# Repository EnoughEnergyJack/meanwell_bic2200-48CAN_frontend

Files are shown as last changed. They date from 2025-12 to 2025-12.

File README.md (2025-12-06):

# Meanwell BIC2200 Front-End Controller

- Many companies develop things that are critical for development, but are not needed for their products/IP. This is one of those developments.
- It is a front-end PCB/Screen that allows you to control the Meanwell BIC2200-48CAN as if it were a Bench PSU, very simple, mostly generated by AI prompts.
- The psu itself is great because it is bidirectional, you can set it as a supply or a regenerative load, up to ~2.2kW.
- If this is useful to you, give Enough Energy Ltd a shoutout, but to be clear this was mostly a "quick and dirty"(but very effective) PCB to help our other developments along.

## Features

- **Display Modes**
  - Main display: Real-time voltage, current, power, and energy monitoring
  - Limits display: Voltage and current setpoint configuration
  
- **Controls**
  - Rotary encoders for voltage (38-65V) and current (0-45A positive, -38A to 0A negative) adjustment
  - Dedicated buttons for output control, view switching, and setpoint confirmation
  
- **Real-Time Monitoring**
  - Output voltage and current readings
  - Power consumption (watts)
  - Energy consumption tracking (watt-hours)
  - Runtime timer
  - Output status indicator
  
- **CAN Bus Communication**
  - Bidirectional communication with Meanwell power supply
  - Automatic setpoint echo verification
  - Real-time data polling

## Hardware

The project uses a dedicated PCB designed specifically for the Arduino Uno. The PCB integrates all required hardware components:

- **16x4 Character LCD Display** (HD44780-compatible)
- **2x Rotary Encoders** with integrated push buttons (voltage and current adjustment)
- **4x Push Buttons** (VIEW, CHNG I, SET BUFFER, OUTPUT)
- **MCP2515 CAN Controller** with CAN transceiver
- **Power Input** (barrel jack connector)
- **Pin Headers** for Arduino Uno connection
- **CAN Bus Connector** for power supply communication

### Wiring Harness

For wiring harness details and external connections, refer to the schematic in the documentation:
- **Schematic**: See `Documentation/Meanwell_FE v17.pdf` for complete wiring diagrams and harness specifications

The PCB is designed to mount directly onto an Arduino Uno, with all components and connections pre-routed on the board.

## Software Dependencies

### Arduino Libraries
- `LiquidCrystal` - LCD display control (included with Arduino IDE)
- `mcp_can` - MCP2515 CAN controller library
- `SPI` - SPI communication (included with Arduino IDE)
- `Encoder` - Rotary encoder input handling

### Installation

1. Install the required libraries via Arduino Library Manager:
   ```
   - mcp_can (by Seeed Studio or compatible)
   - Encoder (by Paul Stoffregen)
   ```

2. Clone or download this repository.

3. Mount the dedicated PCB onto your Arduino Uno (see schematic for pin alignment)

4. Connect the wiring harness as specified in the schematic (`Documentation/Meanwell_FE v17.pdf`)

5. Open `Meanwell/Meanwell.ino` in the Arduino IDE

6. Configure pin assignments in `Meanwell/config.h` if needed (defaults should work with the PCB)

7. Upload the firmware to your Arduino board

## Pin Configuration

Default pin assignments (defined in `config.h`):

| Component | Pin | Description |
|---|-----|---|
| LCD RS | A2 | Register select |
| LCD EN | A3 | Enable |
| LCD D4-D7 | 5, 4, 3, A4 | Data lines (4-bit mode) |
| Voltage Encoder CLK | 6 | Clock pin |
| Voltage Encoder DT | 7 | Data pin |
| Current Encoder CLK | A0 | Clock pin |
| Current Encoder DT | 9 | Data pin |
| SET BUF Button | A1 | Set buffer values |
| OP TOGGLE Button | A5 | Output enable/disable |
| VIEW Button | 8 | Display mode toggle |
| CHNG I Button | 2 | Current direction toggle |
| CAN CS | 10 | CAN controller chip select |

## Usage

### Basic Operation

1. **Setting Voltage and Current Limits**
   - Press VIEW to enter Limits Display mode
   - Rotate voltage encoder to set desired voltage (38-65V)
   - Rotate current encoder to set positive current limit (0-45A)
   - Press CHNG I to switch to negative current editing
   - Rotate current encoder to set negative current limit (-38A to 0A)
   - Press SET BUF to apply settings to the power supply

2. **Enabling Output**
   - Configure desired limits (see above)
   - Press OP TOGGLE to enable output
   - Monitor real-time values on Main Display

3. **Monitoring**
   - Main Display shows:
     - Output voltage (V)
     - Output current (A)
     - Power consumption (W)
     - Energy consumed (Wh)
     - Runtime timer (seconds)
     - Output status (ON/OFF)

For detailed user instructions, see [USER_GUIDE.md](USER_GUIDE.md).

## Technical Details

### CAN Communication

- **Baud Rate**: 250 kbps
- **CAN ID TX**: 0xC0300 (commands to power supply)
- **CAN ID RX**: 0x800C0200 (responses from power supply)
- **Protocol**: PMBus-compatible commands over CAN
- **Mechanism**: Request-response pattern (see [CAN Messaging Protocol](Documentation/CAN_MESSAGING.md) for details)

- Voltage setpoint (CMD_VOUT_SET: 0x20)
- Current setpoint (CMD_IOUT_SET: 0x30)
- Reverse current setpoint (CMD_REVERSE_IOUT_SET: 0x130)
- Output enable/disable (CMD_OPERATION: 0x00)
- Read voltage (CMD_READ_VOUT: 0x60)
- Read current (CMD_READ_IOUT: 0x61)

### Display Update Rates

- Main Display: 20 Hz (50ms intervals)
- Limits Display: 2 Hz (500ms intervals)
- CAN polling: 10 Hz (100ms intervals)

### Energy Tracking

- Energy meter resets when output is enabled
- Power calculation uses filtered values for stability
- Energy integration: `E = ∫ P dt` (watt-hours)

## Development

### Building

1. Ensure all required libraries are installed
2. Open `Meanwell/Meanwell.ino` in Arduino IDE
3. Select your board and port
4. Compile and upload

### Debugging

- Serial output available at 115200 baud
- CAN communication status indicated by blinking `[ ]` on display
- Setpoint echo verification ensures commands are received

## Documentation

- [User Guide](USER_GUIDE.md) - Complete user manual
- [CAN Messaging Protocol](Documentation/CAN_MESSAGING.md) - Detailed explanation of the request-response CAN communication mechanism
- [Documentation/](Documentation/) - Hardware datasheets and specifications
- [MEANWELL.dbc](Documentation/MEANWELL.dbc) - CAN bus DBC file for protocol reference

## License

MIT

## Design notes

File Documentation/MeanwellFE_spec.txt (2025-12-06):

Here is a complete and concise summary of the PCB design in a structured document format:

---

## **Programmable Power Supply Front-End Controller – Design Summary**

### **Overview**

This design implements a front-end user interface and control board for a **Meanwell programmable power supply**, managed via **CAN bus** using an **Arduino microcontroller**. The interface provides user control over voltage and current settings, displays real-time feedback, and communicates settings to the power supply over CAN.

---

### **1. Functional Description**

#### **Main Functions**:

* Allow users to set and buffer **voltage (V)** and **current (I)** values.
* Display real-time output values from the power supply.
* Enable or disable the output via a control button.
* Transmit buffered settings via CAN bus when prompted.

---

### **2. Major Components**

#### **Microcontroller Unit (MCU)**

* **Arduino-compatible board** with:

  * Digital I/O lines for button and display interface
  * CAN bus support via a CAN transceiver module (e.g., MCP2515)

#### **Display**

* **Character LCD** with **parallel interface** (likely HD44780-compatible)

  * Controlled via 4-bit mode (RS, E, D4–D7)
  * Displays:

    * Voltage and current setpoints (`Vset`, `Iset`)
    * Buffered values (`Vbuf`, `Ibuf`)
    * Output readings (`Vout`, `Iout`)
    * Output state (`OP: 1` for ON)

#### **User Input Controls**

* **Two rocker switches**:

  * One for **voltage** adjustment (V+ / V−)
  * One for **current** adjustment (I+ / I−)
* **Two pushbuttons**:

  * `Set Buf`: Sends buffered values to the power supply
  * `OP On/Off`: Toggles power output state

#### **CAN Interface**

* Uses standard **CANH/CANL lines**
* Powered via onboard **+5V** supply
* Connected to Arduino via SPI-compatible CAN module

---

### **3. Power Supply**

* Board is powered via **+5V** input
* Onboard decoupling capacitors for voltage stability
* Supports powering external components including display and CAN transceiver

---

### **4. Connectors**

* **CAN Bus Output Connector**:

  * CANH, CANL
  * +5V and GND
* **Optional headers** for debug or expansion

---

### **5. Signal Flow Summary**

1. **User** adjusts V/I using rocker switches.
2. Adjustments update buffer values (`Vbuf`, `Ibuf`), displayed on screen.
3. **Set Buf** button transmits values to power supply via CAN.
4. **Output button** toggles output enable/disable.
5. Display updates all states and measurements dynamically.

---

### **6. Software Considerations**

* Arduino firmware handles:

  * Button debouncing and state management
  * LCD control using `LiquidCrystal` library
  * CAN bus communication using `MCP_CAN` library or equivalent
  * Control logic for buffering and output toggling

---

### **7. Physical Layout**

* **Compact PCB design** with:

  * Front-facing display
  * Top-mounted rocker and push buttons
  * Rear or side connectors for CAN and power
  * Through-hole and possibly SMD components for ease of assembly

---

### **Applications**

* Laboratory power supply control
* Remote-controlled power systems
* Embedded development requiring voltage/current staging

---

Let me know if you’d like this turned into a PDF or if you want a matching Arduino sketch to go with this design.

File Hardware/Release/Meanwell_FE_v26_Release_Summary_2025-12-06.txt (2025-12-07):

Meanwell_FE v26 - JLCPCB Release Summary
==========================================
Date: 2025-12-06
Version: v26
Board: Meanwell_FE v26

FILES PREPARED:
---------------
1. Meanwell_FE_v26_JLC_PCB.zip
   - Contains all Gerber files and drill file for PCB manufacturing
   - All files in root directory as required by JLCPCB

2. Meanwell_FE_v26_JLCBOM_2025-12-06.csv
   - Bill of Materials in JLCPCB format
   - 21 unique component types
   - 37 total components

3. Meanwell_FE_v26_JLCPNP_2025-12-06.csv
   - Pick and Place file in JLCPCB format
   - 37 components (top and bottom combined)
   - Coordinates in millimeters

COMPONENT STATUS:
-----------------
✓ Components with JLCPCB Part Numbers (10 types):
  - 100nF 0603 capacitors (C1, C6, C8): C105907
  - 1uF 0603 capacitors (C9, C12): C15849
  - 10uF 0805 capacitors (C34, C35, C36, C37): C2922480
  - 120R 0603 resistors (R2, R4): C122081
  - 1k 0603 resistors (R1, R3): C22765
  - M7 diode (D1): C95872
  - NCP1117ST50T3G voltage regulator (U7): C156196
  - CRE1S0505S DC-DC converter (PS1): C7465127
  - 8MHz ceramic resonator (Y1): C341522
  - 43650-0424 connector (J1): C492464

⚠ Components Needing JLCPCB Part Numbers (11 types):
  - 164G_FC_BW-3LP LCD display (DS1) - May need to source separately
  - ESP32-DEVKITC-32E module (U2) - Module, may need extended parts
  - MCP2515-I/SO CAN controller (U1) - Check JLCPCB availability
  - ISO1050DUB CAN transceiver (U4) - Check JLCPCB availability
  - C143785 encoder (VR1, VR2) - PEC12R-4215F-N0024
  - Pin headers (JP2, JP3, JP4, U$2) - Through-hole, may be DNF
  - Switches (CHANGE, OUTPUT, SET_BUFFER, VIEW, I_DOWN, I_UP, V_DOWN, V_UP) - Through-hole, DNF
  - JP1 header - DNF

DNF (Do Not Fit) COMPONENTS:
-----------------------------
These components are marked as DNF and will be hand-soldered or sourced separately:
  - JP1 (1X02 header)
  - I_DOWN, I_UP, V_DOWN, V_UP (momentary switches)
  - All through-hole components

NOTES:
------
1. PCB Manufacturing:
   - Upload Meanwell_FE_v26_JLC_PCB.zip to JLCPCB
   - Board appears to be 2-layer based on file structure
   - Verify board dimensions and specifications during upload

2. Assembly Service:
   - Upload Meanwell_FE_v26_JLCBOM_2025-12-06.csv for BOM
   - Upload Meanwell_FE_v26_JLCPNP_2025-12-06.csv for PnP
   - Review component availability before ordering
   - Many components may need to be sourced as "Extended" parts or separately

3. Component Sourcing:
   - LCD display (164G_FC_BW-3LP) likely needs separate sourcing
   - ESP32 module may be available as extended part
   - Through-hole components (switches, headers) are DNF
   - Verify all IC part numbers match JLCPCB inventory

4. Quality Checks:
   - ✓ BOM component count matches PnP count (37 components)
   - ✓ All designators accounted for
   - ✓ Coordinates in millimeters
   - ✓ Top/bottom layers properly designated
   - ⚠ Some components need JLCPCB part number verification

NEXT STEPS:
----------
1. Review BOM file and add missing JLCPCB part numbers
2. Verify PnP coordinates look correct (compare with Gerber preview)
3. Check component availability on JLCPCB website
4. Update BOM with any part number corrections
5. Upload all files to JLCPCB
6. Review JLCPCB preview carefully before ordering
7. Consider ordering small prototype quantity first (5 boards)

PROCESSING NOTES:
-----------------
- Files processed using process_for_jlc.py script
- BOM parsed from Fusion Electronics export format
- PnP files combined from front and back layers
- Component matching uses preferred_jlcpcb_parts.txt library
- Format follows JLCPCB_Processing_Guide.md specifications

---
End of Release Summary

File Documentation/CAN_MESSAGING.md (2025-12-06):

# Meanwell Power Supply CAN Messaging Protocol

## Overview

The Meanwell power supply uses a **request-response** CAN bus communication protocol based on PMBus commands. Unlike typical CAN implementations where messages are broadcast, this system requires explicit requests to read values, and uses an echo mechanism to verify setpoints.

## CAN Bus Configuration

- **Baud Rate**: 250 kbps
- **CAN ID TX** (Controller → Power Supply): `0xC0300`
- **CAN ID RX** (Power Supply → Controller): `0xC0200`
- **Protocol**: PMBus-compatible commands over CAN

## Message Types

### 1. Read Requests (2-byte messages)

To read a value from the power supply, the controller sends a **2-byte request** containing only the command code:

**Request Format:**
```
Byte 0: Command code (LSB)
Byte 1: Command code (MSB)
```

**Response Format:**
```
Byte 0: Command code (LSB)
Byte 1: Command code (MSB)
Byte 2: Value (LSB) - in hundredths (0.01 units)
Byte 3: Value (MSB) - in hundredths (0.01 units)
```

**Example - Reading Voltage:**
```
Request:  [0x60, 0x00]  (CMD_READ_VOUT = 0x0060)
Response: [0x60, 0x00, 0xE8, 0x03]  (0x03E8 = 1000 → 10.00V)
```

**Example - Reading Current:**
```
Request:  [0x61, 0x00]  (CMD_READ_IOUT = 0x0061)
Response: [0x61, 0x00, 0x64, 0x00]  (0x0064 = 100 → 1.00A)
```

### 2. Write Commands (4-byte messages)

To set a value, the controller sends a **4-byte message** with the command and value:

**Write Format:**
```
Byte 0: Command code (LSB)
Byte 1: Command code (MSB)
Byte 2: Value (LSB) - in hundredths (0.01 units)
Byte 3: Value (MSB) - in hundredths (0.01 units)
```

**Example - Setting Voltage:**
```
Write: [0x20, 0x00, 0xE8, 0x03]  (CMD_VOUT_SET = 0x0020, 0x03E8 = 10.00V)
```

**Example - Setting Current:**
```
Write: [0x30, 0x00, 0x64, 0x00]  (CMD_IOUT_SET = 0x0030, 0x0064 = 1.00A)
```

### 3. Output Control (3-byte messages)

To enable/disable the output, the controller sends a **3-byte message**:

**Format:**
```
Byte 0: Command code (LSB) - CMD_OPERATION = 0x0000
Byte 1: Command code (MSB)
Byte 2: State (0 = OFF, 1 = ON)
```

**Example:**
```
Enable:  [0x00, 0x00, 0x01]
Disable: [0x00, 0x00, 0x00]
```

## Command Codes

| Command | Code (Hex) | Code (Dec) | Description |
|---|---|---|---|
| `CMD_OPERATION` | 0x0000 | 0 | Output enable/disable |
| `CMD_VOUT_SET` | 0x0020 | 32 | Set voltage setpoint |
| `CMD_IOUT_SET` | 0x0030 | 48 | Set positive current setpoint |
| `CMD_FAULT_STATUS` | 0x0040 | 64 | Read fault status |
| `CMD_READ_VIN` | 0x0050 | 80 | Read input voltage |
| `CMD_READ_VOUT` | 0x0060 | 96 | Read output voltage |
| `CMD_READ_IOUT` | 0x0061 | 97 | Read output current |
| `CMD_READ_FAN_SPEED1` | 0x0070 | 112 | Read fan speed 1 |
| `CMD_READ_FAN_SPEED2` | 0x0071 | 113 | Read fan speed 2 |
| `CMD_SCALING_FACTOR` | 0x00C0 | 192 | Scaling factor |
| `CMD_SYSTEM_STATUS` | 0x00C1 | 193 | System status |
| `CMD_SYSTEM_CONFIG` | 0x00C2 | 194 | System configuration |
| `CMD_DIRECTION_CTRL` | 0x0100 | 256 | Direction control |
| `CMD_REVERSE_VOUT_SET` | 0x0120 | 288 | Set reverse voltage |
| `CMD_REVERSE_IOUT_SET` | 0x0130 | 304 | Set negative current |
| `CMD_BIDIRECTIONAL_CONFIG` | 0x0140 | 320 | Bidirectional configuration |

## Value Encoding

All values are encoded as **16-bit integers in hundredths** (0.01 units):

- **Voltage**: 10.00V = `0x03E8` (1000 in decimal)
- **Current**: 1.00A = `0x0064` (100 in decimal)
- **Power**: Calculated from V × I (not directly read)

**Encoding Formula:**
```cpp
uint16_t encoded = (uint16_t)(value * 100);
byte lsb = encoded & 0xFF;
byte msb = (encoded >> 8) & 0xFF;
```

**Decoding Formula:**
```cpp
uint16_t encoded = (rxBuf[3] << 8) | rxBuf[2];
float value = encoded * 0.01;
```

## Timing Considerations

### Delays Between Messages

The code includes strategic delays to ensure proper communication:

- **After setpoint writes**: 50ms delay between voltage, positive current, and negative current
- **After output state**: 10ms delay
- **Echo timeout**: 50ms maximum wait for response

### Polling Intervals

- **Real-time values**: 100ms (10 Hz) - alternates V/I
- **Setpoint echo**: 100ms (10 Hz) - cycles through all setpoints
- **Display updates**: 50ms (20 Hz) for main display, 500ms (2 Hz) for limits display

## Message Flow Examples

### Example 1: Setting Voltage and Current Limits

```
1. Controller sends: [0x20, 0x00, 0xE8, 0x03]  (Set 10.00V)
   Delay 50ms
   
2. Controller sends: [0x30, 0x00, 0x64, 0x00]  (Set 1.00A positive)
   Delay 50ms
   
3. Controller sends: [0x30, 0x01, 0x32, 0x00]  (Set 0.50A negative)
   
4. Controller requests echo: [0x20, 0x00]
   Power supply responds: [0x20, 0x00, 0xE8, 0x03]  ✓ Verified
   
5. Controller requests echo: [0x30, 0x00]
   Power supply responds: [0x30, 0x00, 0x64, 0x00]  ✓ Verified
   
6. Controller requests echo: [0x30, 0x01]
   Power supply responds: [0x30, 0x01, 0x32, 0x00]  ✓ Verified
```

### Example 2: Reading Real-Time Values

```
Time 0ms:
  Controller sends: [0x60, 0x00]  (Request voltage)
  Power supply responds: [0x60, 0x00, 0xE8, 0x03]  (10.00V)

Time 100ms:
  Controller sends: [0x61, 0x00]  (Request current)
  Power supply responds: [0x61, 0x00, 0x64, 0x00]  (1.00A)

Time 200ms:
  Controller sends: [0x60, 0x00]  (Request voltage)
  Power supply responds: [0x60, 0x00, 0xE9, 0x03]  (10.01V)
  
...continues alternating...
```

### Example 3: Enabling Output

```
1. Controller sends: [0x00, 0x00, 0x01]  (Enable output)
   Delay 10ms
   
2. Controller continues polling for voltage/current to monitor output
```

## Why This Protocol is "Weird"

1. **Mixed Message Sizes**: 
   - Read requests: 2 bytes
   - Write commands: 4 bytes
   - Output control: 3 bytes
   - Responses: 4 bytes

2. **No Broadcast Updates**: The power supply never sends unsolicited messages. All communication is initiated by the controller.

## Troubleshooting

### No Response from Power Supply

1. Check CAN bus wiring (CAN_H, CAN_L, GND)
2. Verify CAN baud rate (250 kbps)
3. Check CAN ID filters
4. Verify power supply is powered and in CAN mode

### Setpoint Not Applied

1. Check echo verification - if echo doesn't match, setpoint wasn't accepted
2. Verify value is within power supply limits
3. Check for fault conditions
4. Ensure proper delays between setpoint messages

### Missing Updates

1. Verify polling is active (check `canPacketsReceived` counter)
2. Check display update rates
3. Verify CAN receive buffer isn't full (code flushes after each read)

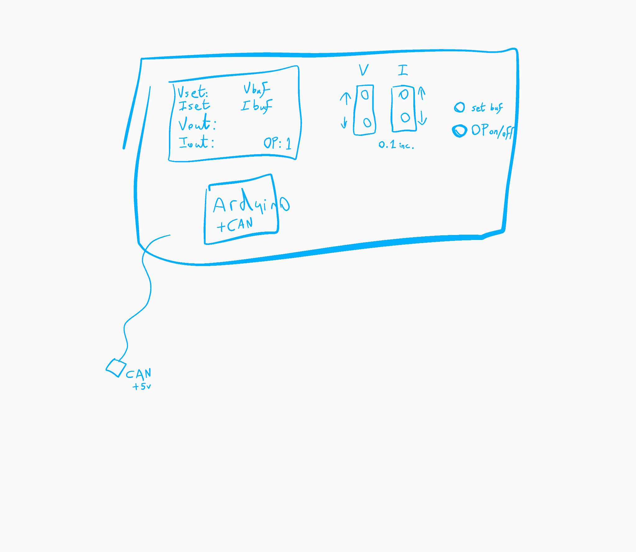
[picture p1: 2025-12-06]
Documentation/Controller_Block_Diagram.png

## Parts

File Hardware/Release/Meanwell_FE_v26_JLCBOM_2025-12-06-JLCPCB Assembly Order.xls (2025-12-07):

JLCPCB BOM Tool - BOM Matching
BOM name：Meanwell_FE_v26_JLCBOM_2025-12-06-JLCPCB Assembly Order.xlsx |  |  | Download Time：2025-12-07 08:08:08 |  |  |  | * Our matching results are updated in real-time, but stock and prices may change. If it's been over 24 hours, please re-match before placing your order.
PCB Assembled Qty：5 |  |  | Est. Total Price：38.7453
Your BOM |  |  |  |  | Matched Parts |  |  |  |  |  |  | Order Information
Top Designator | Bottom Designator | Comment | Footprint | JLCPCB Part # | Matches | Part # | Manufacturer | Footprint | Description | Category | Warning | JLCPCB Part # | Product link | Lib Type | Qty | Source | Total Price ($)
 | C1,C6,C8 | 100nF | CAPC1608X85 |  | Select by System | C0603X104K101T | IHHEC(HOLY STONE ENTERPRISE CO., LTD) | 0603 | 100V 100nF X7R ±10% 0603 Multilayer Ceramic Capacitors MLCC - SMD/SMT ROHS | Multilayer Ceramic Capacitors MLCC - SMD/SMT |  | C105907 | https://jlcpcb.com/partdetail/107122-C0603X104K101T/C105907 | Extended | 25 | 25 JLCPCB | 0.1475
 | C12,C9 | 1uF | CAPC1608X85 |  | Select by System | CL10A105KB8NNNC | Samsung Electro-Mechanics | 0603 | 1uF 50V X5R ±10% 0603 Multilayer Ceramic Capacitors MLCC - SMD/SMT ROHS | Multilayer Ceramic Capacitors MLCC - SMD/SMT |  | C15849 | https://jlcpcb.com/partdetail/16531-CL10A105KB8NNNC/C15849 | Basic | 20 | 20 JLCPCB | 0.094
 | C34,C35,C36,C37 | 10uF | CAPC2012X110 |  | Select by System | CL21A106KAYNNNE | Samsung Electro-Mechanics | 0805 | 10uF 25V X5R 0805 Multilayer Ceramic Capacitors MLCC - SMD/SMT ROHS | Multilayer Ceramic Capacitors MLCC - SMD/SMT |  | C2922480 | https://jlcpcb.com/partdetail/3232961-CL21A106KAYNNNE/C2922480 | Extended | 30 | 30 JLCPCB | 0.441
CHANGE,OUTPUT,SET_BUFFER,VIEW |  | C455095 | SWITCH-MOMENTARY-PTH-6.5MM |  | Unconfirmed | TS-1002-07026 | XUNPU | 插件-4P,6x6mm | 100,000 Cycles 12V 2.6N 50mA 6mm 6mm 7mm Black PC Pin Round Button SPST Through Hole Without Bracket Plugin-4P,6x6mm Tactile Switches ROHS | Tactile Switches | 1.There may be multiple types of parts, but one type of part has been matched. Please check.; | C455095 | https://jlcpcb.com/partdetail/XUNPU-TS_100207026/C455095 | Extended | 21 | 21 JLCPCB | 0.7623
 | D1 | M7 | SMB |  | Select by System | M7 | MDD(Microdiode Semiconductor) | SMA(DO-214AC) | -55℃~+150℃ 1.1V@1A 1A 1kV 30A 5uA@1kV Independent SMA(DO-214AC) Diodes - General Purpose ROHS | Diodes - General Purpose |  | C95872 | https://jlcpcb.com/partdetail/MDD_Microdiode_Semiconductor-M7/C95872 | Basic | 15 | 15 JLCPCB | 0.117
 | J1 | 43650-0424 | 43650-04YY_242526 |  | Select by Customer | 436500424 | MOLEX | SMD,P=3mm | -40℃~+105℃ 1 1x4P 3mm 4 4P 600V 8.5A 9.9mm Auxiliary Solder Pin Black Brass Micro-Fit(MX 3.0) Surface Mount,Vertical Tin UL94V-0 SMD,P=3mm Wire To Board Connector ROHS | Wire To Board Connector |  | C122400 | https://jlcpcb.com/partdetail/MOLEX-436500424/C122400 | Extended | 5 | 5 JLCPCB | 6.2475
 | JP2,JP4 | C5156616 | 1X08-BIG |  | Select by Customer | KH-2.54PH180-1X8P-L11.5 | Shenzhen Kinghelm Elec | 插件,P=2.54mm | -40℃~+105℃ 1 1x8P 2.54mm 2.5mm 3A 3mm 6mm 8P Black Pin Header Through Hole Plugin,P=2.54mm Pin Headers ROHS | Pin Headers |  | C2905487 | https://jlcpcb.com/partdetail/3175225-KH_2_54PH180_1X8P_L115/C2905487 | Extended | 10 | 10 JLCPCB | 0.804
 | JP3 | C5156615 | 1X06-BIG |  | Select by System | 2.54-1*6 | ZHOURI | 插件,P=2.54mm | -40℃~+105℃ 1 1x6P 2.54mm 2.54mm 2.5A 3mm 6P 6mm Brass Gold Pin Header Through Hole Plugin,P=2.54mm Pin Headers ROHS | Pin Headers |  | C5156615 | https://jlcpcb.com/partdetail/ZHOURI-2_54_16/C5156615 | Extended | 5 | 5 JLCPCB | 0.1735
 | PS1 | CRE1S0505S | CRE1(SC) |  | Select by System | B0505S-1W | EVISUN | SIP-4 | -45℃~+85℃ 1 1.5kV 100uF 1W 200mA 23mA 4.5V~5.5V 5V 60mVp-p 77kHz 79% SIP-4 Isolated Power Modules ROHS | Isolated Power Modules |  | C7465127 | https://jlcpcb.com/partdetail/EVISUN-B0505S1W/C7465127 | Extended | 5 | 5 JLCPCB | 2.79
 | R1,R3 | 1k | RESC1608X60 |  | Select by System | 0603WAF1201T5E | UNI-ROYAL(Uniroyal Elec) | 0603 | -55℃~+155℃ 1.2kΩ 100mW 75V Thick Film Resistor ±1% ±100ppm/℃ 0603 Chip Resistor - Surface Mount ROHS | Chip Resistor - Surface Mount |  | C22765 | https://jlcpcb.com/partdetail/23492-0603WAF1201T5E/C22765 | Basic | 20 | 20 JLCPCB | 0.024
 | R2,R4 | 120R | RESC1608X60 |  | Select by Customer | 0603WAF1200T5E | UNI-ROYAL(Uniroyal Elec) | 0603 | -55℃~+155℃ 100mW 120Ω 75V Thick Film Resistor ±1% ±100ppm/℃ 0603 Chip Resistor - Surface Mount ROHS | Chip Resistor - Surface Mount |  | C22787 | https://jlcpcb.com/partdetail/23514-0603WAF1200T5E/C22787 | Basic | 20 | 20 JLCPCB | 0.024
 | U1 | MCP2515-I/SO | SOIC127P1030X265-18N |  | Select by Customer | MCP2515T-I/SO | Microchip Tech | SOIC-18-300mil | -40℃~+85℃ 1Mbps 1uA 2.7V~5.5V 5mA CAN Controller SPI SOIC-18-300mil CAN Controllers ROHS | CAN Controllers | 1.The comment (MCP2515T-I/SO) of this part does not match the one (MCP2515-I/SO) provided in your BOM. Please confirm; | C153782 | https://jlcpcb.com/partdetail/MicrochipTech-MCP2515T_ISO/C153782 | Extended | 5 | 5 JLCPCB | 6.7725
 | U4 | ISO1050DUB | SOP254P1040X485-8 |  | Select by Customer | ISO1050DUBR | Texas Instruments | SOP-8 | -55℃~+105℃ 1 1Mbps 2500 3V~5.5V 4.75V~5.25V 50kV/us SOP-8 Isolated CAN Transceivers ROHS | Isolated CAN Transceivers |  | C16428 | https://jlcpcb.com/partdetail/TexasInstruments-ISO1050DUBR/C16428 | Extended | 5 | 5 JLCPCB | 2.5425
 | U7 | NCP1117ST50T3G | SOT223 |  | Select by System | NCV1117ST50T3G | onsemi | SOT-223 | -40℃~+125℃ 1 1.2V@(800mA) 150uVrms 1A 20V 5V 61dB@(120Hz) 6mA Fixed Over Current Protection Positive SOT-223 Voltage Regulators - Linear, Low Drop Out (LDO) Regulators ROHS | Voltage Regulators - Linear, Low Drop Out (LDO) Regulators |  | C156196 | https://jlcpcb.com/partdetail/onsemi-NCV1117ST50T3G/C156196 | Extended | 5 | 5 JLCPCB | 1.3015
 | U$2 | C5156617 | 1X10-BIG |  | Select by System | 2.54-1*10 | ZHOURI | 插件,P=2.54mm | 1 10P 1x10P 2.54mm Plugin,P=2.54mm Pin Headers ROHS | Pin Headers |  | C5156617 | https://jlcpcb.com/partdetail/ZHOURI-2_54_110/C5156617 | Extended | 5 | 5 JLCPCB | 0.2095
VR1,VR2 |  | C143785 | PEC12R4215FN0024 |  | Select by System | PEC12R-4220F-N0024 | BOURNS | 插件 | Plugin Rotary Encoders ROHS | Rotary Encoders |  | C143785 | https://jlcpcb.com/partdetail/BOURNS-PEC12R_4220FN0024/C143785 | Extended | 10 | 10 JLCPCB | 15.435
 | Y1 | 8MHz | OSC_CSTNE8M00GH5C000R0 |  | Select by System | CSTNE8M00G550000R0 | Murata Electronics | SMD3213-3P | -40℃~+85℃ 33pF 40Ω 8MHz SMD3213-3P Ceramic Resonators ROHS | Ceramic Resonators |  | C341522 | https://jlcpcb.com/partdetail/318914-CSTNE8M00G550000R0/C341522 | Extended | 5 | 5 JLCPCB | 0.8595
 | U2 | ESP32-DEVKITC-32E | MODULE_ESP32-DEVKITC-32E |  | Select by System | ESP32-DevKitC-32E | Espressif Systems | THrough hole | THrough hole Modules | Global Sourcing Parts |  | C19183942 | https://jlcpcb.com/partdetail/EspressifSystems-ESP32_DevKitC32E/C19183942 | Extended | 5 | 0 JLCPCB | 0
DS1 |  | 164G_FC_BW-3LP | 164GFCBW3LP |  | No matches | No Part Selected
I_DOWN,I_UP,V_DOWN,V_UP |  | DNF | SWITCH-MOMENTARY-PTH-6.5MM |  | No matches | No Part Selected
JP1 |  | DNF | 1X02 |  | No matches | No Part Selected

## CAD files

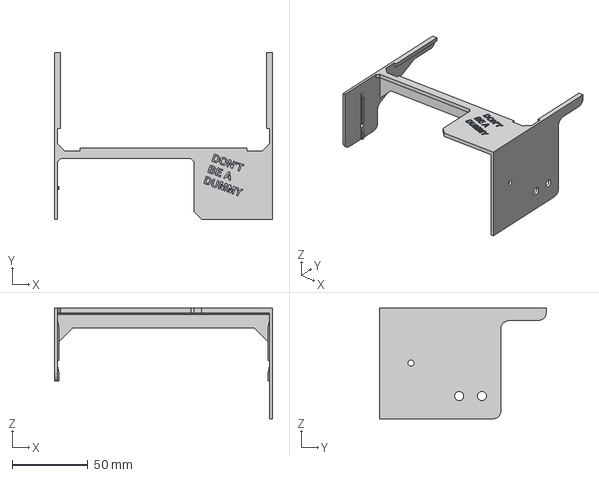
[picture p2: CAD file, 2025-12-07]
Hardware/MEANWELL BRACKET.step
144.0 x 110.0 x 73.0 mm

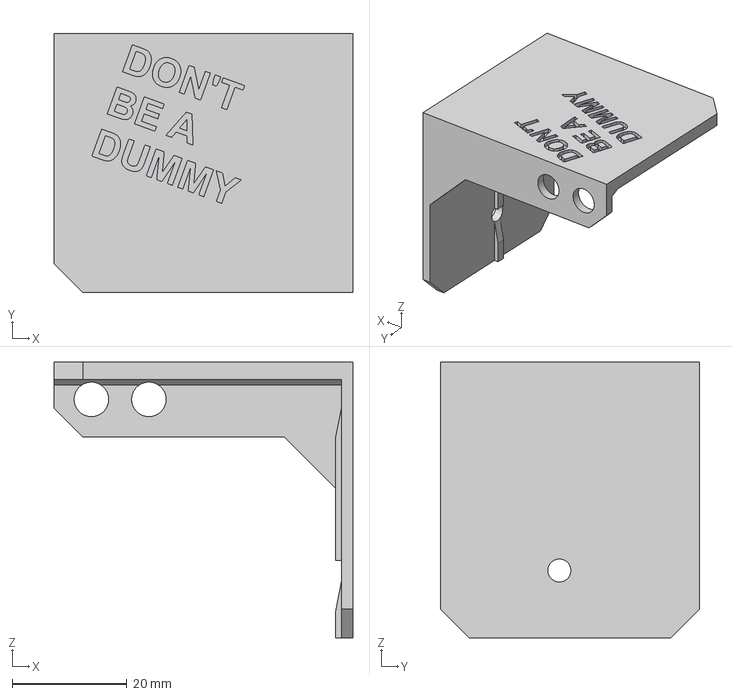
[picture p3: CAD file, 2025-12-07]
Hardware/Mechanical/MEANWELL BRACKET_SMALL.step
52.0 x 45.0 x 48.0 mm

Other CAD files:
Hardware/Mechanical/MEANWELL BRACKET.step
Hardware/Mechanical/MEANWELL BRACKET v3.stl
Hardware/Mechanical/MEANWELL BRACKET_SMALL v3.stl
Hardware/DesignFiles/Meanwell_FE.f3z
Hardware/Mechanical/MEANWELL BRACKET.f3d

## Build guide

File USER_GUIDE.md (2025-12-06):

# Meanwell Bench Power Supply - User Guide

## Overview
This is a bench power supply controller with a 16x4 character LCD display. You can set voltage and current limits, monitor output, and track energy consumption.

## Display Modes

### Main Display (Default)
The main display shows real-time measurements and status:

```
V: XX.XXV        sec:XXX
I: XX.XXA
P: XX.XXW        OP:ON
E: XXXWh         [  ]
```

- **V**: Output voltage (volts)
- **I**: Output current (amps)
- **P**: Power consumption (watts)
- **E**: Energy consumed (watt-hours)
- **sec**: Timer showing how long the output has been enabled (in seconds)
- **OP**: Output status (ON or OFF)
- **[ ]**: Communication indicator (blinks when receiving data)

### Limits Display
Press the **VIEW** button to switch to the limits display:

```
LIMITS          BUF
Vs : XX.X < XX.X
I+ : XX.X < XX.X
I- : XX.X < XX.X
```

- **Vs**: Voltage setpoint (the target voltage)
- **I+**: Positive current limit
- **I-**: Negative current limit
- **<**: Arrow indicating which value you're editing
- **BUF**: Buffer values (temporary values you adjust before setting)

## Controls

### Rotary Encoders

1. **Voltage Encoder** (left knob)
   - Rotate to adjust the voltage buffer value
   - Range: 38.0V to 65.0V
   - Adjusts in 0.1V steps

2. **Current Encoder** (right knob)
   - Rotate to adjust the current buffer value
   - Which current limit you're editing depends on the **CHNG I** button state:
     - **I+** (positive current): 0.0A to 45.0A
     - **I-** (negative current): -38.0A to -0.001A
   - Adjusts in 0.1A steps

### Buttons

1. **VIEW Button**
   - Switches between Main Display and Limits Display
   - Press to toggle between the two views

2. **CHNG I Button**
   - Switches between editing positive current (I+) and negative current (I-)
   - The arrow (**<**) on the display shows which current limit you're currently editing
   - Only visible in Limits Display mode

3. **SET BUF Button**
   - Applies the buffer values as the actual setpoints
   - Press this button to confirm your voltage and current settings
   - The setpoints are sent to the power supply after pressing this button
   - Only works in Limits Display mode

4. **OP TOGGLE Button**
   - Turns the output ON or OFF
   - When turning ON, the timer and energy meter reset to zero
   - When turning OFF, the timer pauses and retains its value
   - Works in both display modes

## Basic Operation

### Setting Voltage and Current Limits

1. Press **VIEW** to switch to Limits Display
2. Rotate the **Voltage Encoder** to set your desired voltage (38-65V)
3. Rotate the **Current Encoder** to set the positive current limit (0-45A)
4. Press **CHNG I** to switch to negative current editing
5. Rotate the **Current Encoder** to set the negative current limit (-38A to 0A)
6. Press **SET BUF** to apply these settings to the power supply
7. The display will briefly show confirmation, then return to Main Display if output is enabled

### Enabling Output

1. Set your desired voltage and current limits (see above)
2. Press **OP TOGGLE** to turn the output ON
3. The display will show "OUTPUT STATE : ON" briefly
4. Monitor voltage, current, power, and energy on the Main Display

### Monitoring Operation

- Watch the **Main Display** for real-time measurements
- The **timer** shows how long the output has been enabled
- The **energy meter (E)** tracks total energy consumption in watt-hours
- The **power (P)** shows instantaneous power draw

### Disabling Output

- Press **OP TOGGLE** to turn the output OFF
- The timer will pause and retain its value
- Energy consumption stops accumulating

## Tips

- The buffer values are temporary until you press **SET BUF**
- The timer and energy meter reset when you turn the output ON
- If output is enabled, the display automatically returns to Main Display after setting limits
- The communication indicator (**[ ]**) blinks to show the controller is receiving data from the power supply

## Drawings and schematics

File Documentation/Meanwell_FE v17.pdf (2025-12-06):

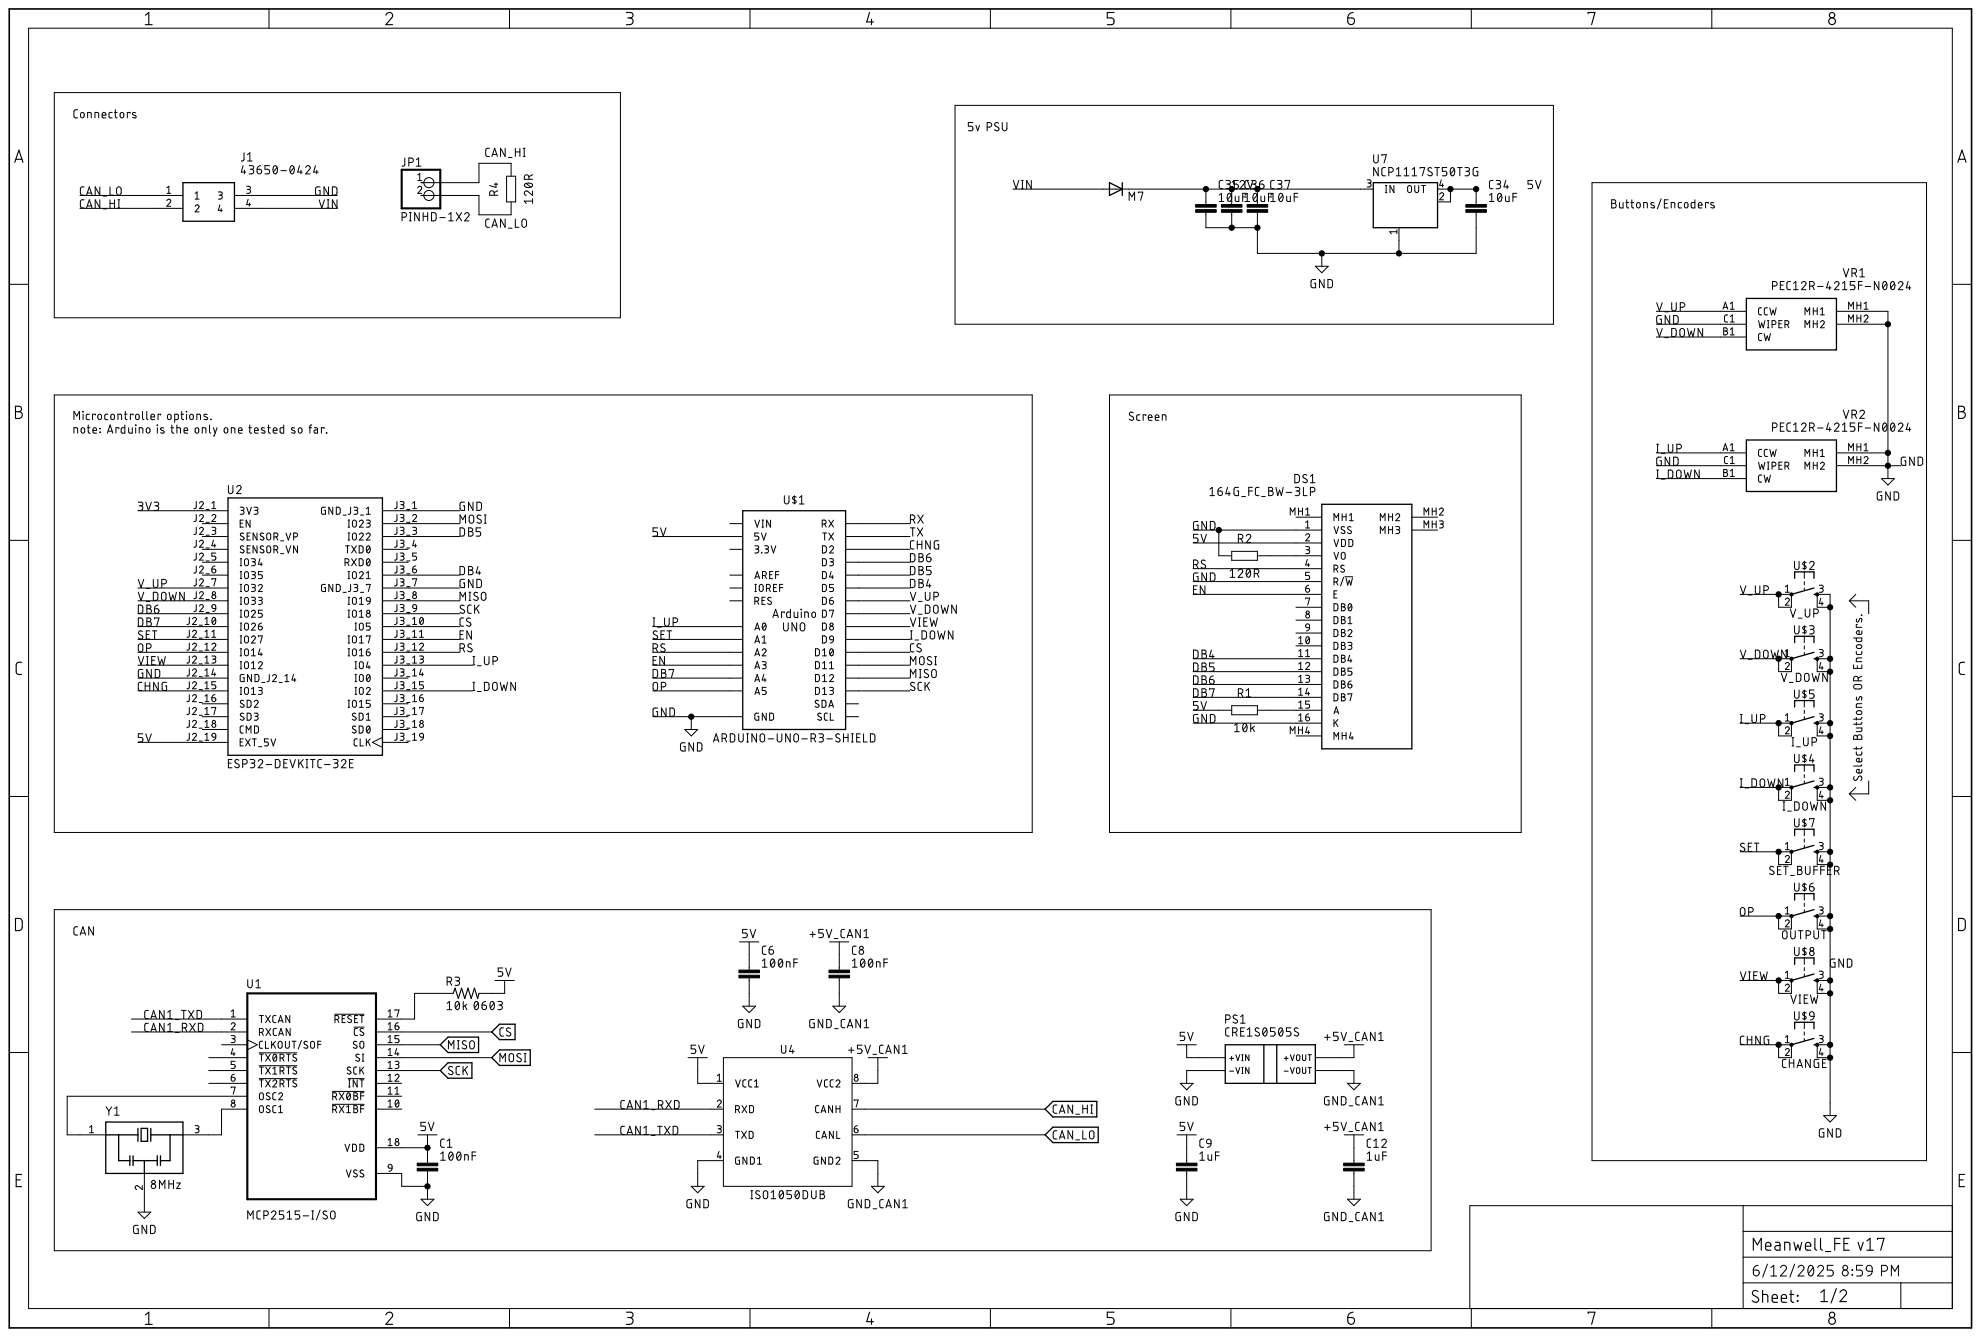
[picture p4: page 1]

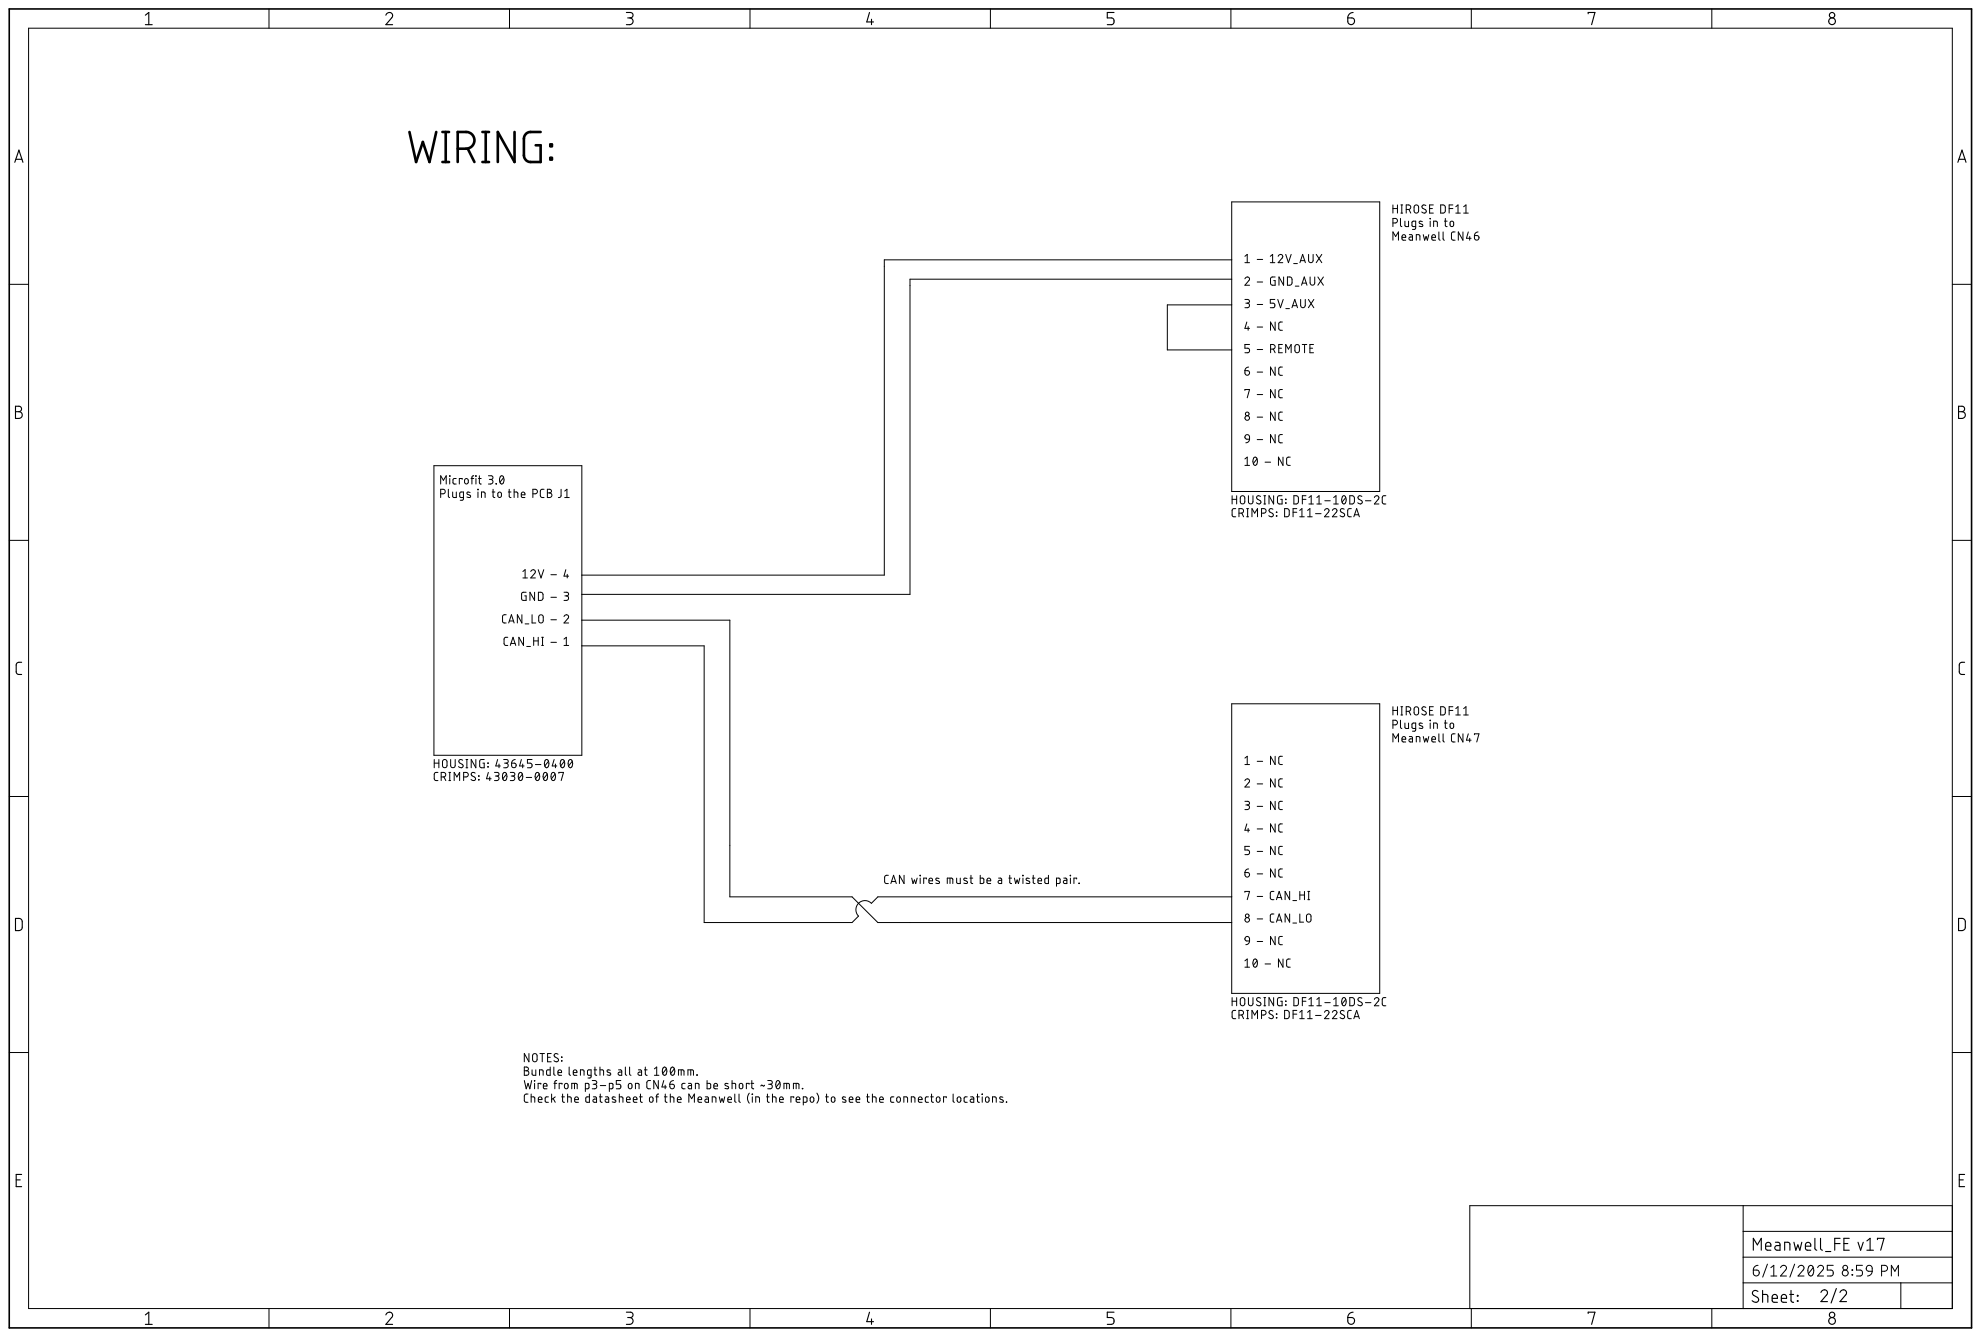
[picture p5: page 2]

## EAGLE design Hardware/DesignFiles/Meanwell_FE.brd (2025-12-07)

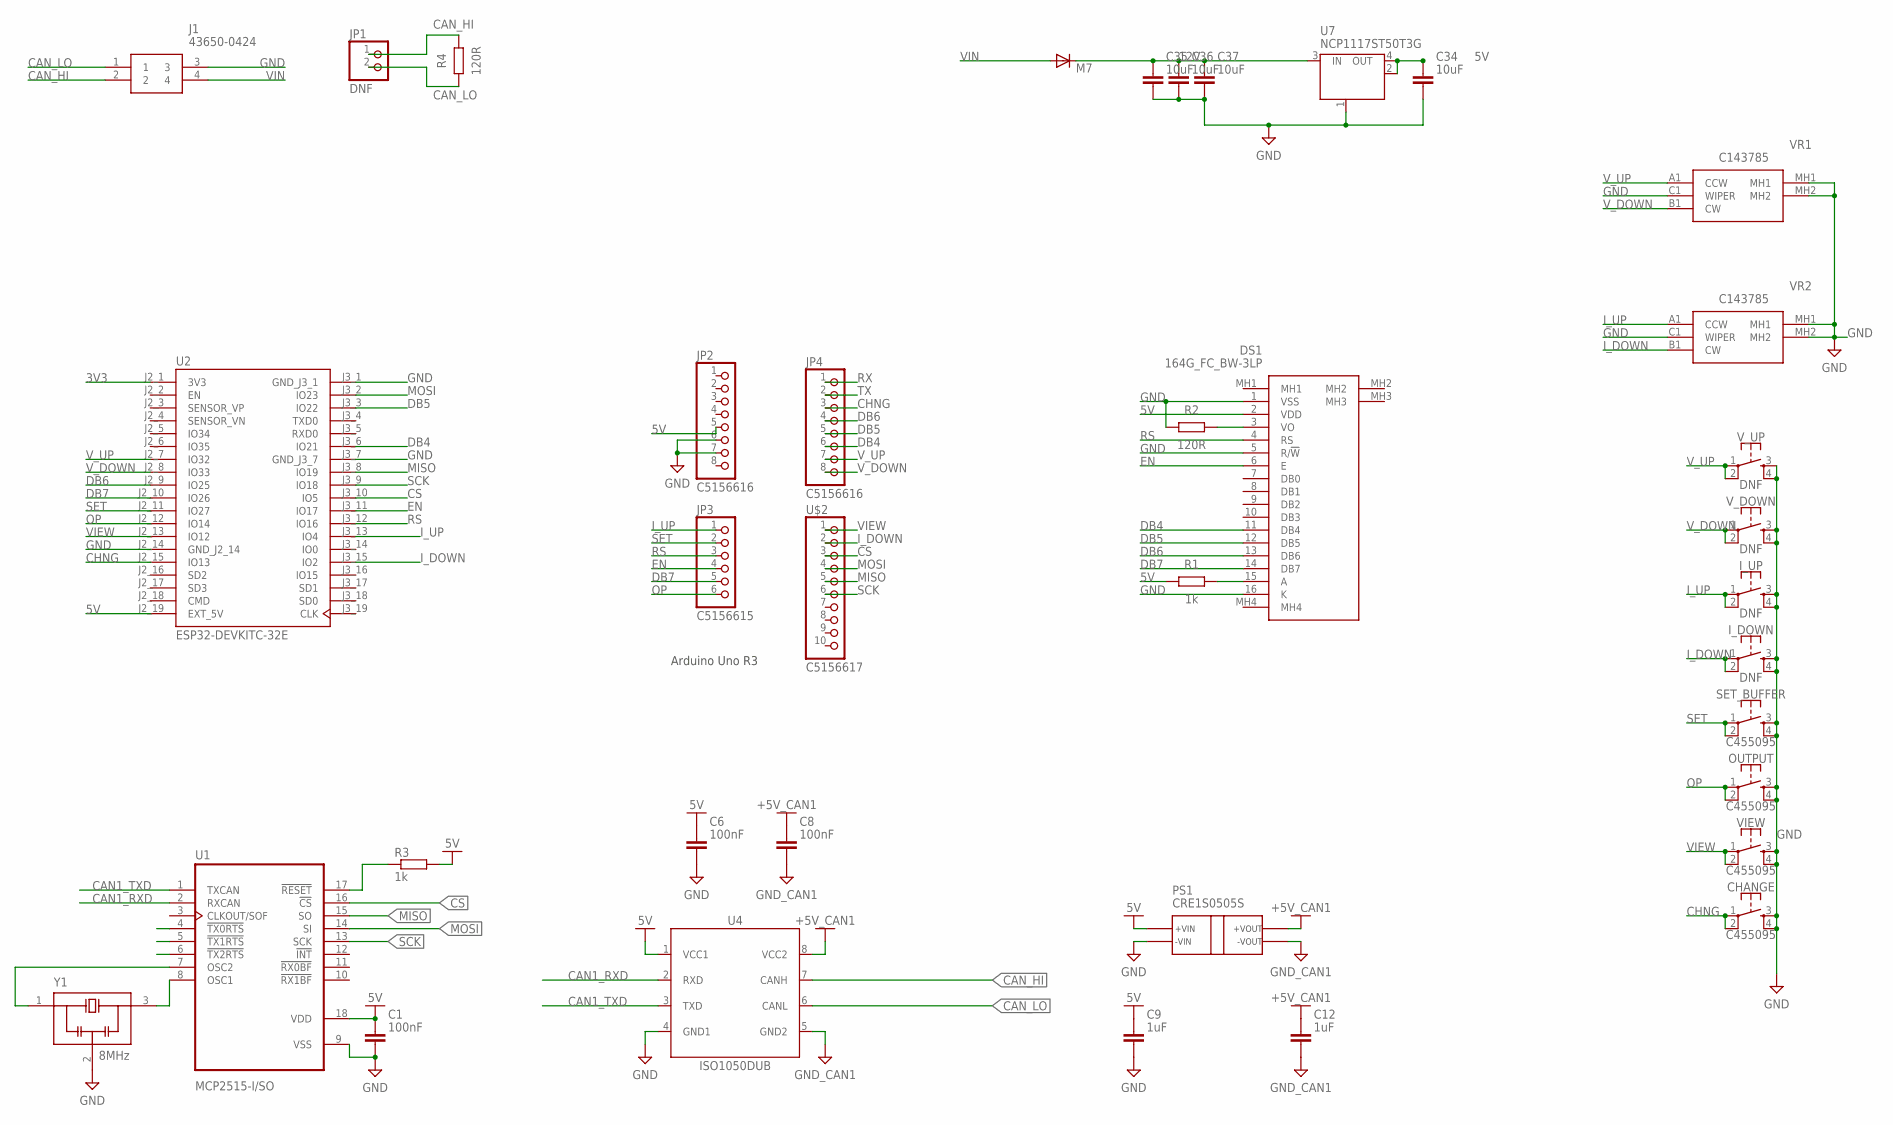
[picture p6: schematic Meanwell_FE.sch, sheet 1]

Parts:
C1, C6, C8: 100nF; CAPC1608X85
C9, C12: 1uF; CAPC1608X85
C34, C35, C36, C37: 10uF; CAPC2012X110
CHANGE: C455095; SWITCH-MOMENTARY-PTH-6.5MM
D1: M7; SMB
DS1: 164G_FC_BW-3LP; 164GFCBW3LP
I_DOWN: DNF; SWITCH-MOMENTARY-PTH-6.5MM
I_UP: DNF; SWITCH-MOMENTARY-PTH-6.5MM
J1: 43650-0424; 43650-04YY_242526
JP1: DNF; 1X02
JP2, JP4: C5156616; 1X08-BIG
JP3: C5156615; 1X06-BIG
OUTPUT: C455095; SWITCH-MOMENTARY-PTH-6.5MM
PS1: CRE1S0505S; CRE1(SC)
R1, R3: 1k; RESC1608X60
R2, R4: 120R; RESC1608X60
SET_BUFFER: C455095; SWITCH-MOMENTARY-PTH-6.5MM
U1: MCP2515-I/SO; SOIC127P1030X265-18N
U2: ESP32-DEVKITC-32E; MODULE_ESP32-DEVKITC-32E
U4: ISO1050DUB; SOP254P1040X485-8
U7: NCP1117ST50T3G; SOT223
U$2: C5156617; 1X10-BIG
VIEW: C455095; SWITCH-MOMENTARY-PTH-6.5MM
VR1, VR2: C143785; PEC12R4215FN0024
V_DOWN: DNF; SWITCH-MOMENTARY-PTH-6.5MM
V_UP: DNF; SWITCH-MOMENTARY-PTH-6.5MM
Y1: 8MHz; OSC_CSTNE8M00GH5C000R0

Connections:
3V3: U2.J2_1 (3V3)
5V: C1.1, C6.1, C9.1, C34.1, DS1.2 (VDD), JP2.5, PS1.2 (+VIN), R1.1, R3.2, U1.18 (VDD), U2.J2_19 (EXT_5V), U4.1 (VCC1), U7.2 (OUT), U7.4 (OUT)
12V: C35.1, C36.1, C37.1, D1.C, U7.3 (IN)
+5V_CAN1: C8.1, C12.1, PS1.4 (+VOUT), U4.8 (VCC2)
CAN1_RXD: U1.2 (RXCAN), U4.2 (RXD)
CAN1_TXD: U1.1 (TXCAN), U4.3 (TXD)
CAN_HI: J1.2, JP1.1, R4.2, U4.7 (CANH)
CAN_LO: J1.1, JP1.2, R4.1, U4.6 (CANL)
CHNG: CHANGE.1, CHANGE.2, JP4.3, U2.J2_15 (IO13)
CS: U1.16 (!CS), U2.J3_10 (IO5), U$2.3
DB4: DS1.11 (DB4), JP4.6, U2.J3_6 (IO21)
DB5: DS1.12 (DB5), JP4.5, U2.J3_3 (IO22)
DB6: DS1.13 (DB6), JP4.4, U2.J2_9 (IO25)
DB7: DS1.14 (DB7), JP3.5, U2.J2_10 (IO26)
EN: DS1.6 (E), JP3.4, U2.J3_11 (IO17)
GND: C1.2, C6.2, C9.2, C34.2, C35.2, C36.2, C37.2, CHANGE.3, CHANGE.4, DS1.1 (VSS), DS1.5 (R/!W), DS1.16 (K), I_DOWN.3, I_DOWN.4, I_UP.3, I_UP.4, J1.3, JP2.6, JP2.7, OUTPUT.3, OUTPUT.4, PS1.1 (-VIN), R2.1, SET_BUFFER.3, SET_BUFFER.4, U1.9 (VSS), U2.J2_14 (GND_J2_14), U2.J3_1 (GND_J3_1), U2.J3_7 (GND_J3_7), U4.4 (GND1), U7.1 (GND/ADJ), VIEW.3, VIEW.4, VR1.C1 (WIPER), VR1.MH1, VR1.MH2, VR2.C1 (WIPER), VR2.MH1, VR2.MH2, V_DOWN.3, V_DOWN.4, V_UP.3, V_UP.4, Y1.2 (GND)
GND_CAN1: C8.2, C12.2, PS1.3 (-VOUT), U4.5 (GND2)
I_DOWN: I_DOWN.1, I_DOWN.2, U2.J3_15 (IO2), U$2.2, VR2.B1 (CW)
I_UP: I_UP.1, I_UP.2, JP3.1, U2.J3_13 (IO4), VR2.A1 (CCW)
MISO: U1.15 (SO), U2.J3_8 (IO19), U$2.5
MOSI: U1.14 (SI), U2.J3_2 (IO23), U$2.4
unnamed: DS1.3 (VO), R2.2
unnamed: U1.7 (OSC2), Y1.1 (IN)
unnamed: DS1.15 (A), R1.2
unnamed: R3.1, U1.17 (!RESET)
unnamed: U1.8 (OSC1), Y1.3 (OUT)
OP: JP3.6, OUTPUT.1, OUTPUT.2, U2.J2_12 (IO14)
RS: DS1.4 (RS), JP3.3, U2.J3_12 (IO16)
RX: JP4.1
SCK: U1.13 (SCK), U2.J3_9 (IO18), U$2.6
SET: JP3.2, SET_BUFFER.1, SET_BUFFER.2, U2.J2_11 (IO27)
TX: JP4.2
VIEW: U2.J2_13 (IO12), U$2.1, VIEW.1, VIEW.2
VIN: D1.A, J1.4
V_DOWN: JP4.8, U2.J2_8 (IO33), VR1.B1 (CW), V_DOWN.1, V_DOWN.2
V_UP: JP4.7, U2.J2_7 (IO32), VR1.A1 (CCW), V_UP.1, V_UP.2

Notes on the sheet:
Arduino Uno R3

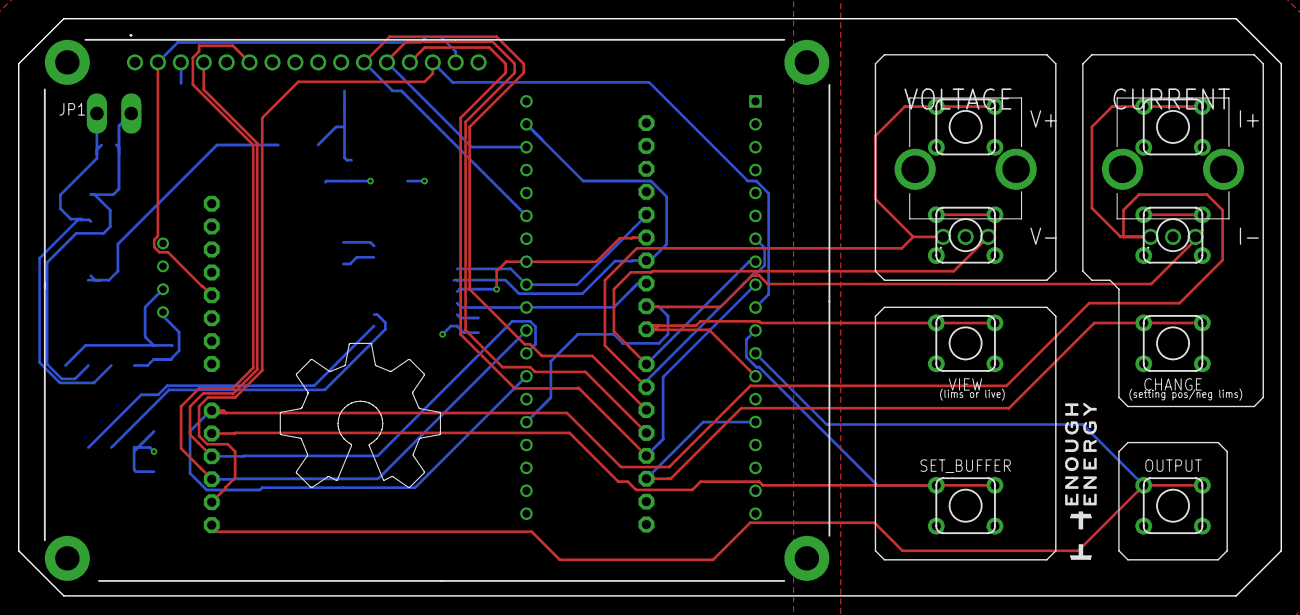
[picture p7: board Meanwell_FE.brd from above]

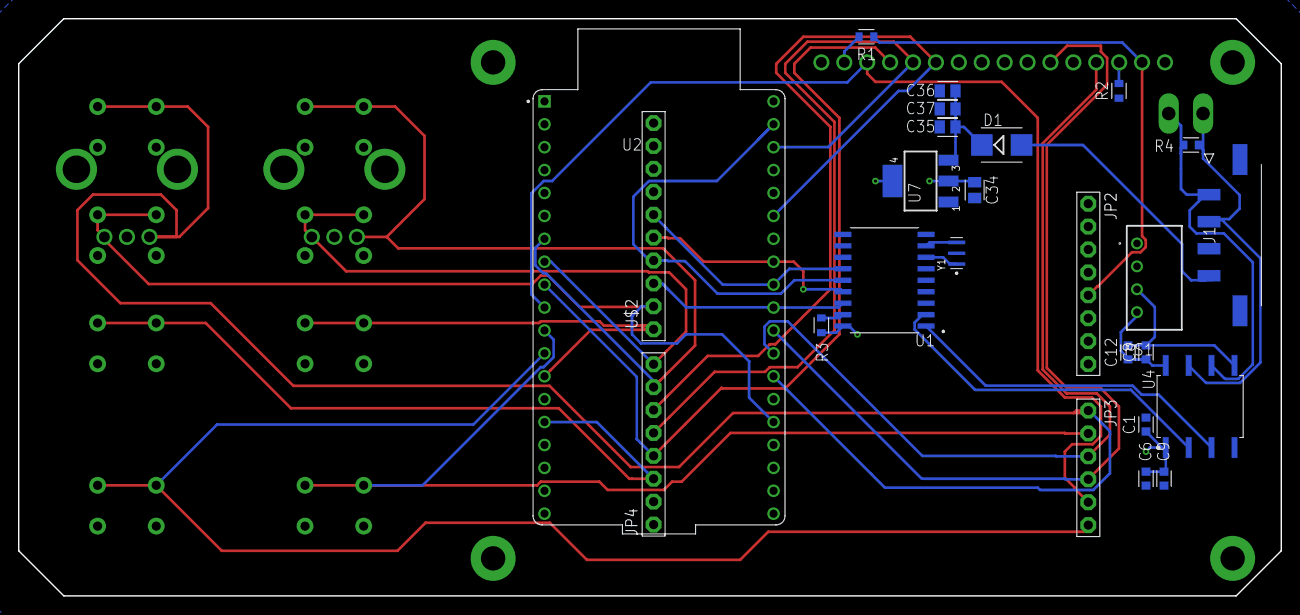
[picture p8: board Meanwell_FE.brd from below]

Board: 2 copper layers, 140.0 x 64.0 mm, 37 parts (25 on the bottom side), 33 nets.

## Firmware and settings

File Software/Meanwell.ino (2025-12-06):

#include "config.h"
#include "can_comm.h"
#include "display.h"
#include "inputs.h"
#include <mcp_can.h>
#include <SPI.h>
#include <LiquidCrystal.h>

// Global variable definitions
float vSet = 0.0;
float iSetPos = 0.0;
float iSetNeg = -0.0001;
float vBuf = 38.0;
float iBufPos = 0;
float iBufNeg = -0.001;
bool editingIBufNeg = false;
float vOut = 0.0;
float iOut = 0.0;
bool outputEnabled = false;
bool toggle = false;
uint8_t displayMode = 0;
float energyWh = 0.0;
unsigned long lastEnergyUpdate = 0;
unsigned long timerStartMillis = 0;
bool lastOutputEnabled = false;
unsigned long pausedTime = 0;
unsigned long canPacketsReceived = 0;
float filteredPower = 0.0;

MCP_CAN CAN(CAN_CS_PIN);
LiquidCrystal lcd(LCD_RS, LCD_EN, LCD_D4, LCD_D5, LCD_D6, LCD_D7);

void setup() {
  Serial.begin(115200);
  lcd.begin(16, 4);
  lcd.clear();
  lcd.print("Meanwell Ctrl");
  lcd.setCursor(0, 1);
  lcd.print("Initializing...");

  if(CAN.begin(MCP_ANY, CAN_250KBPS, MCP_8MHZ) == CAN_OK) Serial.println("MCP2515 Initialized Successfully!");
  else Serial.println("Error Initializing MCP2515...");

  CAN.setMode(MCP_NORMAL);
  sendOutputState();
  // pinMode(V_ENC_CLK, INPUT_PULLUP);
  // pinMode(V_ENC_DT, INPUT_PULLUP);
  // pinMode(I_ENC_CLK, INPUT_PULLUP);
  // pinMode(I_ENC_DT, INPUT_PULLUP);
  pinMode(SET_BUF_PIN, INPUT_PULLUP);
  pinMode(OP_TOGGLE_PIN, INPUT_PULLUP);
  pinMode(VIEW_PIN, INPUT_PULLUP);
  pinMode(CHNG_I_PIN, INPUT_PULLUP);
  updateDisplay1();
}

void loop() {
  // Read inputs first and frequently for responsiveness
  readInputs();
  
  // Only update slower tasks every few loops
  static unsigned long lastSlowUpdate = 0;
  unsigned long currentTime = millis();
  
  if(displayMode==0 && (currentTime - lastSlowUpdate >= 50)){
    updateEnergyAndState();
    checkOutputReal();
    updateDisplay1();
    sendOutputState();
    lastSlowUpdate = currentTime;
  }
if(displayMode==1 && (currentTime - lastSlowUpdate >= 500)){  // 20Hz for slower tasks
    updateEnergyAndState();
    checkSetpointEcho();
    updateDisplay2();
    sendOutputState();
    lastSlowUpdate = currentTime;
  }
  
  //delay(1);  // Very short delay for encoder responsiveness
}

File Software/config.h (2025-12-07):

#ifndef CONFIG_H
#define CONFIG_H

#include <Arduino.h>

// CAN Configuration
const int CAN_CS_PIN = 10;

// LCD Configuration (4-bit mode)
const int LCD_RS = A2;
const int LCD_EN = A3;
const int LCD_D4 = 5;
const int LCD_D5 = 4;
const int LCD_D6 = 3;
const int LCD_D7 = A4;

// Button and Switch Pins  
const int V_ENC_CLK = 6;       // Voltage rotary encoder CLK pin
const int V_ENC_DT = 7;        // Voltage rotary encoder DT pin
const int I_ENC_CLK = A0;      // Current rotary encoder CLK pin
const int I_ENC_DT = 9;        // Current rotary encoder DT pin
const int SET_BUF_PIN = A1;    // Pushbutton to set buffer
const int OP_TOGGLE_PIN = A5;  // Pushbutton to toggle output
const int VIEW_PIN = 8;
const int CHNG_I_PIN = 2;

// CAN Message IDs (from DBC file)
const unsigned long CAN_ID_TX = 0xC0300;  // ID for sending messages to power supply
const unsigned long CAN_ID_RX = 0x800C0200;  // ID for receiving messages from power supply

// Command values (from DBC file)
const uint16_t CMD_VOUT_SET = 0x20;   // 32
const uint16_t CMD_IOUT_SET = 0x30;   // 48
const uint16_t CMD_OPERATION = 0x00;  // 0
const uint16_t CMD_READ_VOUT = 0x60;  // 96
const uint16_t CMD_READ_IOUT = 0x61;  // 97
const uint16_t CMD_FAULT_STATUS = 0x40; // 64
const uint16_t CMD_READ_VIN = 0x50; // 80
const uint16_t CMD_READ_FAN_SPEED1 = 0x70; // 112
const uint16_t CMD_READ_FAN_SPEED2 = 0x71; // 113
const uint16_t CMD_SCALING_FACTOR = 0xC0; // 192
const uint16_t CMD_SYSTEM_STATUS = 0xC1; // 193
const uint16_t CMD_SYSTEM_CONFIG = 0xC2; // 194
const uint16_t CMD_DIRECTION_CTRL = 0x100; // 256
const uint16_t CMD_REVERSE_VOUT_SET = 0x120; // 288
const uint16_t CMD_REVERSE_IOUT_SET = 0x130; // 304
const uint16_t CMD_BIDIRECTIONAL_CONFIG = 0x140; // 320

// State Variables (extern declarations)
extern float vSet;
extern float iSetPos;
extern float iSetNeg;
extern float vBuf;
extern float iBufPos;
extern float iBufNeg;
extern bool editingIBufNeg;
extern float vOut;
extern float iOut;
extern bool outputEnabled;
extern bool toggle;
extern uint8_t displayMode;
extern float energyWh;
extern unsigned long lastEnergyUpdate;
extern unsigned long timerStartMillis;
extern bool lastOutputEnabled;
extern unsigned long pausedTime;
extern unsigned long canPacketsReceived;
extern float filteredPower;

#endif // CONFIG_H 

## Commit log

2025-12-07 Uploading the hardware files.
    [Meanwell_FE.brd, Meanwell_FE.sch, Meanwell_FE_v26_JLCBOM_2025-12-06-JLCPCB Assembly Order.xls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]
2025-12-07 Rename Meanwell_FE_v26_JLCBOM_2025-12-06-JLCPCB Assembly Order.xls to Hardware/Release/Meanwell_FE_v26_JLCBOM_2025-12-06-JLCPCB Assembly Order.xls
    [Meanwell_FE_v26_JLCBOM_2025-12-06-JLCPCB Assembly Order.xls]
2025-12-07 Update and rename Meanwell_FE_v26_JLCBOM_2025-12-06.csv to Hardware/Release/Meanwell_FE_v26_JLCBOM_2025-12-06.csv
    [Meanwell_FE_v26_JLCBOM_2025-12-06.csv]
2025-12-07 Update and rename Meanwell_FE_v26_JLCPNP_2025-12-06.csv to Hardware/Release/Meanwell_FE_v26_JLCPNP_2025-12-06.csv
    [Meanwell_FE_v26_JLCPNP_2025-12-06.csv]
2025-12-07 Rename Hardware/MEANWELL BRACKET v3.stl to Hardware/Mechanical/MEANWELL BRACKET v3.stl
    [MEANWELL BRACKET v3.stl]
2025-12-07 Rename Hardware/MEANWELL BRACKET.f3d to Hardware/Mechanical/MEANWELL BRACKET.f3d
    [MEANWELL BRACKET.f3d]
2025-12-07 Update and rename Hardware/MEANWELL BRACKET.step to Hardware/Mechanical/MEANWELL BRACKET.step
    [MEANWELL BRACKET.step]
2025-12-07 Rename Hardware/MEANWELL BRACKET_SMALL v3.stl to Hardware/Mechanical/MEANWELL BRACKET_SMALL v3.stl
    [MEANWELL BRACKET_SMALL v3.stl]
2025-12-07 Update and rename Hardware/MEANWELL BRACKET_SMALL.step to Hardware/Mechanical/MEANWELL BRACKET_SMALL.step
    [MEANWELL BRACKET_SMALL.step]
2026-09-13 Fix CAN message processing in can_comm.cpp
    Drain all queued CAN messages per loop instead of one, decode the
    full 16-bit command byte, drop power smoothing in favor of raw
    values, and add debug logging for received/unmatched CAN IDs.
    Ported from the Bitbucket meanwell_fe repo's in-progress CAN fix.
    [can_comm.cpp]
